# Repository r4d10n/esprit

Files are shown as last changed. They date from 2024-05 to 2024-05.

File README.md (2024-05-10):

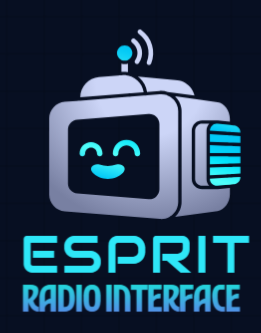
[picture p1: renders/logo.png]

# ESPRIT
ESP Radio Interface - Through Hole version with ESP32 DOIT devboard (based on [ESPRI](https://github.com/kamilsss655/ESPRI) project)

ESPRI project provides an integrated Digital Audio / Programming Interface for Quangsheng UV-K5, Baofeng UV-5R and other Kenwood-style connector radios, similar to the excellent [AIOC](https://github.com/skuep/AIOC) project. With ESP32 offering WiFi/Bluetooth connectivity,  the possibilities are endless !

Since Lolin32 Lite is not common in this part of the world and SMD sourcing / assembly is still cumbersome, we've attempted a Through Hole version for the most common 30 pin [ESP32 DOIT board](https://mischianti.org/doit-esp32-dev-kit-v1-high-resolution-pinout-and-specs/).

Changes:

- Since there are a lot of unpopulated I/Os, we've added 0.91" OLED, couple of LEDs, Switches and one more Touchpad Button. 
- The ADC/DAC IO pins have been broken out to a header
- Header Pins for Radio PWR, 5v and 3.3v 
- SMD 2N7002 has been replaced with THT 2N7000  

[[Interactive BOM]](https://htmlpreview.github.io/?https://github.com/r4d10n/esprit/blob/main/ibom/ibom.html) - [[Schematics]](https://kicanvas.org/?github=https://github.com/r4d10n/esprit/blob/main/espri-doit.kicad_sch) - [[PCB]](https://kicanvas.org/?github=https://github.com/r4d10n/esprit/blob/main/espri-doit.kicad_pcb) - [[Gerbers]](https://github.com/r4d10n/esprit/blob/main/production/espri-doit.zip)

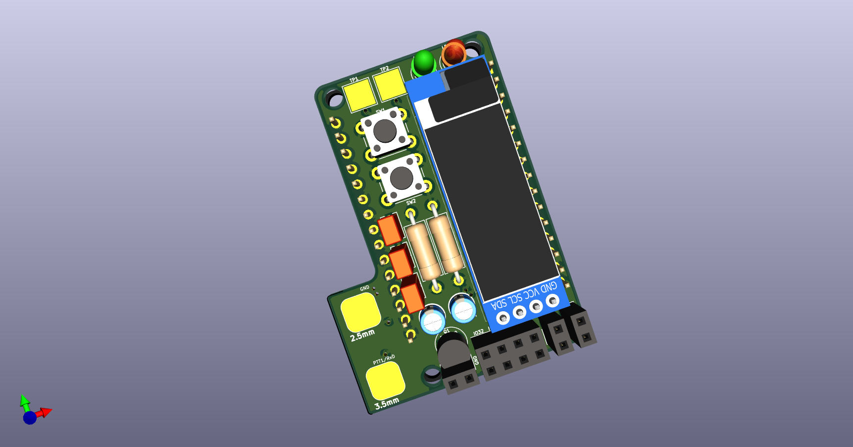
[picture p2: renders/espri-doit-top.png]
Top Render

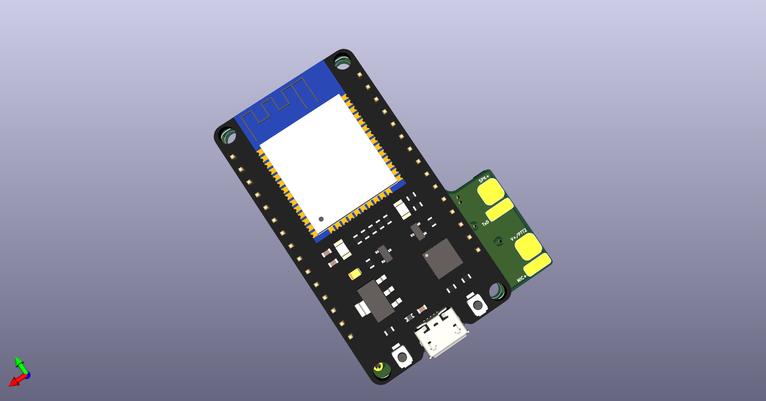
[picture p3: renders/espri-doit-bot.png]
Bottom Render

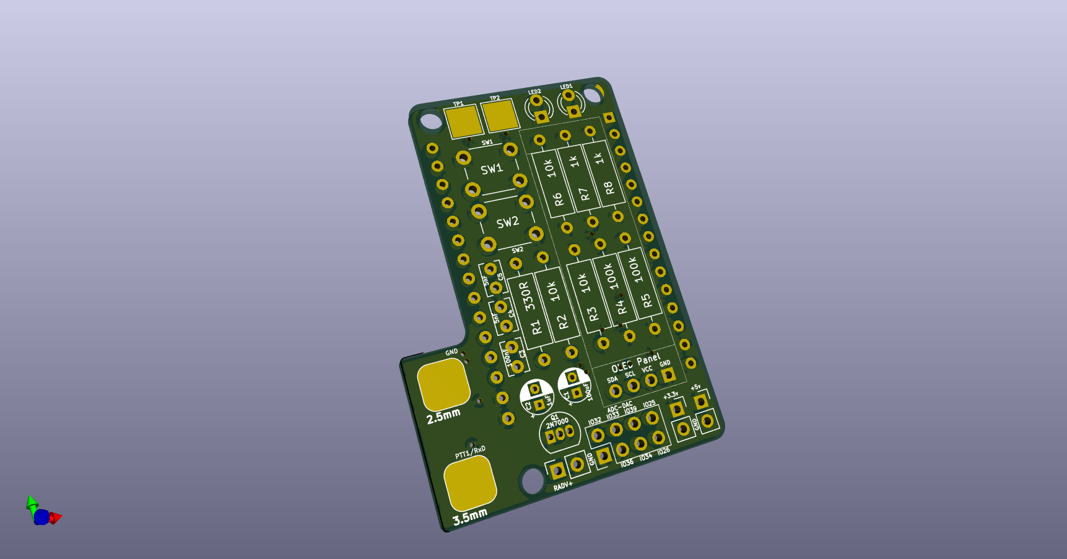
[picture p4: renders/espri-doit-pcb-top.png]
Top PCB Render

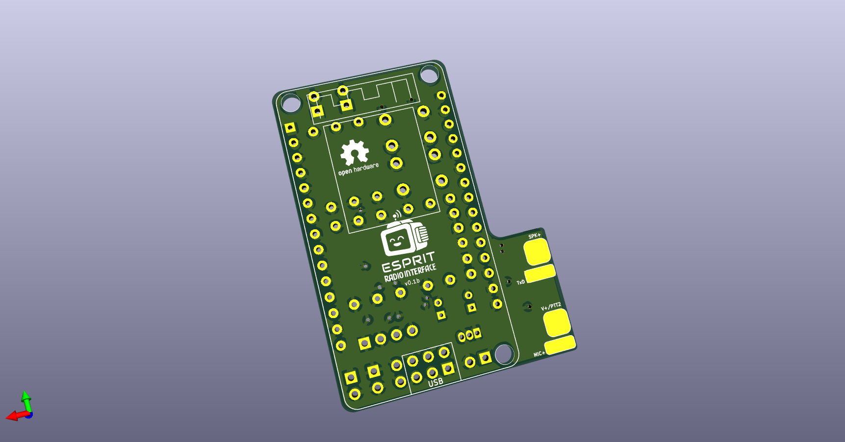
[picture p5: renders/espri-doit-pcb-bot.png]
Bottom PCB Render


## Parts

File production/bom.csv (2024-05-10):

Designator | Footprint | Quantity | Value | LCSC Part #
C1 | CP_Radial_D4.0mm_P2.00mm | 1 | 100uF
C2 | CP_Radial_D4.0mm_P2.00mm | 1 | 1uF
C3 | C_Rect_L4.0mm_W2.5mm_P2.50mm | 1 | 100nF
C4, C5 | C_Rect_L4.0mm_W2.5mm_P2.50mm | 2 | 5nF
D1 | OLED 0.91 128x38 | 1 | ~
D2, D3 | LED_D3.0mm | 2 | LED
J1 | Rig Audio Connector | 1 | ~
J2, J3, J5 | PinSocket_1x02_P2.54mm_Vertical | 3 | Conn_01x02_Pin
J4 | PinSocket_2x04_P2.54mm_Vertical | 1 | Conn_02x04_Top_Bottom
Q1 | TO-92_Inline | 1 | 2N7000
R1 | R_Axial_DIN0309_L9.0mm_D3.2mm_P12.70mm_Horizontal | 1 | 330R
R2, R3, R6 | R_Axial_DIN0309_L9.0mm_D3.2mm_P12.70mm_Horizontal | 3 | 10k
R4, R5 | R_Axial_DIN0309_L9.0mm_D3.2mm_P12.70mm_Horizontal | 2 | 100k
R7, R8 | R_Axial_DIN0309_L9.0mm_D3.2mm_P12.70mm_Horizontal | 2 | 1k
SW1, SW2 | SW_PUSH_6mm_H4.3mm | 2 | SW_Push
TP1, TP2 | TestPoint_Pad_4.0x4.0mm | 2 | TestPoint_Probe
U1 | esp32 devkit doit | 1 | ESP32_DevKit_V1_DOIT

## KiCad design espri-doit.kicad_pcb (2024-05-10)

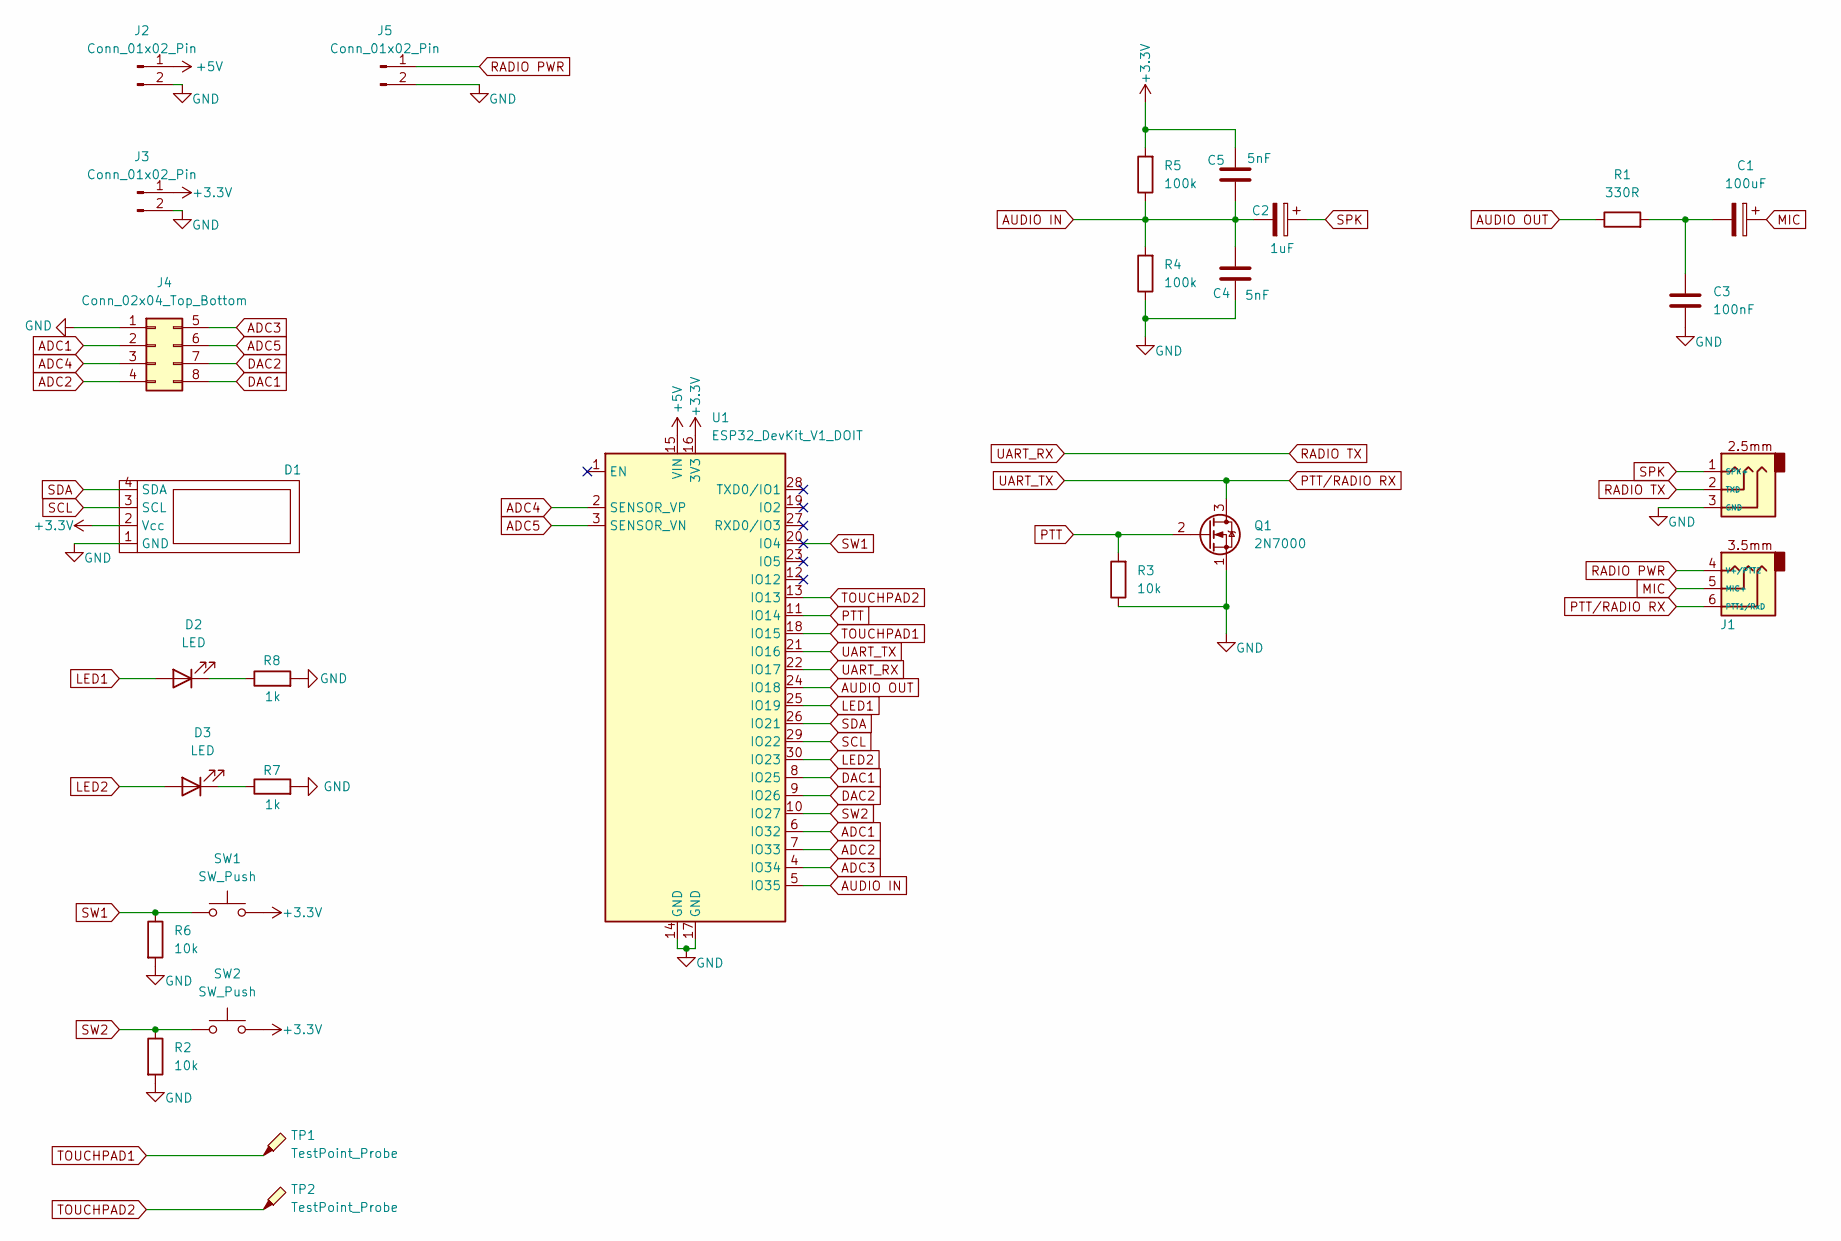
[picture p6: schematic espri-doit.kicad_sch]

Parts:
C1: 100uF; CP_Radial_D4.0mm_P2.00mm
C2: 1uF; CP_Radial_D4.0mm_P2.00mm
C3: 100nF; C_Rect_L4.0mm_W2.5mm_P2.50mm
C4, C5: 5nF; C_Rect_L4.0mm_W2.5mm_P2.50mm
D1: OLED 0.91 128x38
D2, D3: LED; LED_D3.0mm
J1: Rig Audio Connector
J2, J3, J5: Conn_01x02_Pin; PinSocket_1x02_P2.54mm_Vertical
J4: Conn_02x04_Top_Bottom; PinHeader_2x04_P2.54mm_Vertical
Q1: 2N7000; TO-92_Inline
R1: 330R; R_Axial_DIN0309_L9.0mm_D3.2mm_P12.70mm_Horizontal
R2, R3, R6: 10k; R_Axial_DIN0309_L9.0mm_D3.2mm_P12.70mm_Horizontal
R4, R5: 100k; R_Axial_DIN0309_L9.0mm_D3.2mm_P12.70mm_Horizontal
R7, R8: 1k; R_Axial_DIN0309_L9.0mm_D3.2mm_P12.70mm_Horizontal
SW1, SW2: SW_Push; SW_PUSH_6mm_H4.3mm
TP1, TP2: TestPoint_Probe; TestPoint_Pad_4.0x4.0mm
U1: ESP32_DevKit_V1_DOIT; esp32 devkit doit

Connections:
+3.3V: C5.1, D1.2 (Vcc), J3.1, R5.2, SW1.2, SW2.2, U1.16 (3V3)
+5V: J2.1, U1.15 (VIN)
ADC1: J4.2, U1.6 (IO32)
ADC2: J4.4, U1.7 (IO33)
ADC3: J4.5, U1.4 (IO34)
ADC4: J4.3, U1.2 (SENSOR_VP)
ADC5: J4.6, U1.3 (SENSOR_VN)
AUDIO IN: C2.2, C4.1, C5.2, R4.2, R5.1, U1.5 (IO35)
AUDIO OUT: R1.1, U1.24 (IO18)
DAC1: J4.8, U1.8 (IO25)
DAC2: J4.7, U1.9 (IO26)
GND: C3.2, C4.2, D1.1 (GND), J1.3 (GND), J2.2, J3.2, J4.1, J5.2, Q1.1 (S), R2.2, R3.1, R4.1, R6.2, R7.2, R8.2, U1.14 (GND), U1.17 (GND)
LED1: D2.2 (A), U1.25 (IO19)
LED2: D3.2 (A), U1.30 (IO23)
MIC: C1.1, J1.5 (MIC+)
unnamed: C1.2, C3.1, R1.2
unnamed: D2.1 (K), R8.1
unnamed: D3.1 (K), R7.1
PTT: Q1.2 (G), R3.2, U1.11 (IO14)
PTT/RADIO RX: J1.6 (PTT1/RxD), Q1.3 (D), U1.21 (IO16)
RADIO PWR: J1.4 (V+/PTT2), J5.1
RADIO TX: J1.2 (TXD), U1.22 (IO17)
SCL: D1.3 (SCL), U1.29 (IO22)
SDA: D1.4 (SDA), U1.26 (IO21)
SPK: C2.1, J1.1 (SPK+)
SW1: R6.1, SW1.1, U1.20 (IO4)
SW2: R2.1, SW2.1, U1.10 (IO27)
TOUCHPAD1: TP1.1, U1.18 (IO15)
TOUCHPAD2: TP2.1, U1.13 (IO13)

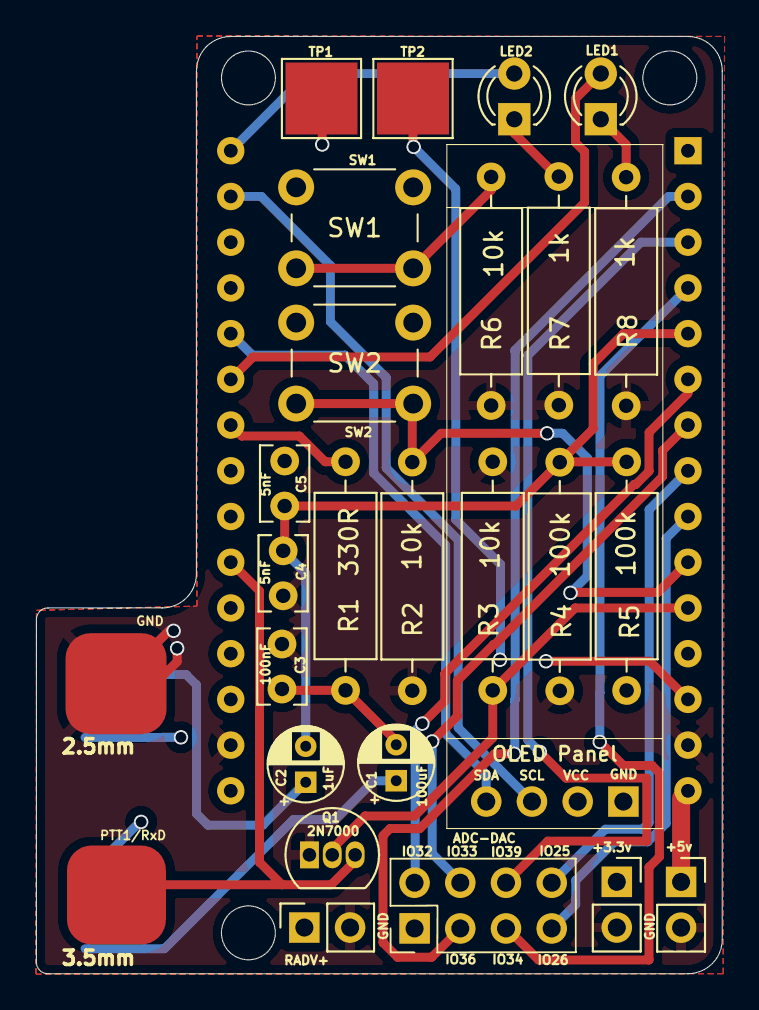
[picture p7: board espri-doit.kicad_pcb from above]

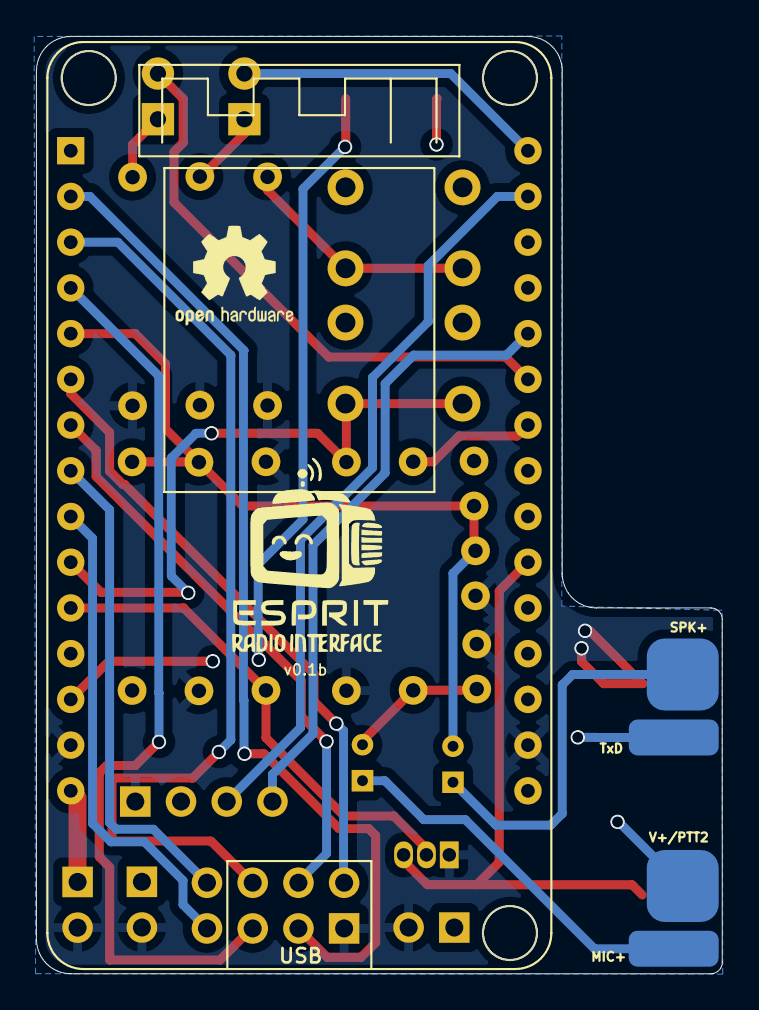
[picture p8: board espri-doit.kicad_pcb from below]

Board: 4 copper layers, 38.1 x 52.1 mm, 27 parts (3 on the bottom side), 29 nets.
